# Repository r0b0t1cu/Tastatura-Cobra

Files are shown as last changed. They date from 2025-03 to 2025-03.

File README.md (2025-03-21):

# [RO] Tastatură Custom pentru Cobra & ZX Spectrum  

Acesta este un proiect open-source pentru o tastatură mecanică compatibilă cu computerul românesc **Cobra** și alte clone **ZX Spectrum**.
Tastatura a fost proiectată pentru a fi ușor de construit, utilizând componente accesibile.  

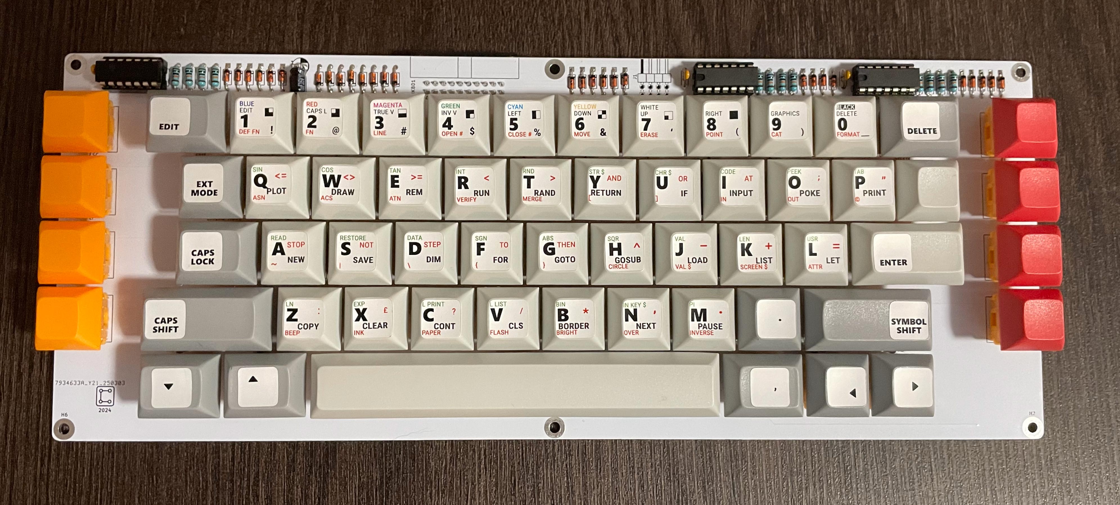
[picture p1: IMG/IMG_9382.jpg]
Tastatură completă


## Caracteristici  
- **Compatibilitate:** Cobra, ZX Spectrum și clone  
- **Conexiune:** Cablu panglică 2x10, conector montat pe partea inferioară a PCB-ului
- **Componente principale:**  
  - 59 Switch-uri mecanice cu 3 pini din plastic  
  - 3 x **IC CD4066**  
  - 29 x **diode BAT42**  
  - 12 x **rezistențe 100k**  
  - 1 x **condensator 10uF**  
  - 3 x **condensator 100nF**  
  - 1 x **conector 2x10 pini**  
  - optional - 1 x **conector 2x4 pini**
- **Funcționalitate extinsă:**
  - Taste speciale pentru CP/M pe Cobra
  - Taste separate pentru: del, cursor, caps lock, edit, extended mode, "." (punct), "," (virgula), ":" (doua puncte)

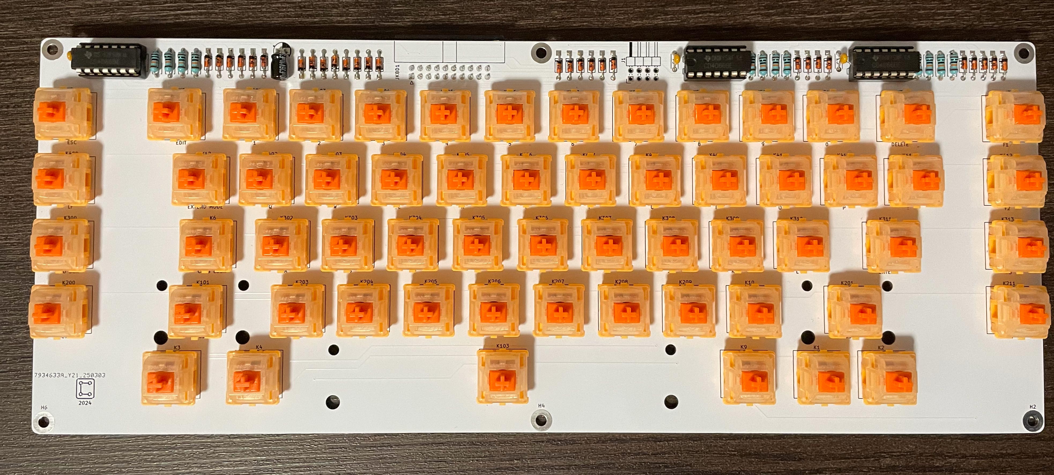
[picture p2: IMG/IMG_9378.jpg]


## Instalare și Conectare  
1. **Montaj PCB:** Conectorul cablului panglică **trebuie montat pe partea inferioară** a PCB-ului.  
2. **Pentru Cobra:** Se conectează direct la interfața tastaturii.  
3. **Pentru ZX Spectrum și clone:** Se identifică manual liniile și coloanele din matrice și se ajustează conexiunile corespunzător. 
4. Tastatura este gândită să se potrivească pe carcasa de aici:
   - [https://www.z80-romania.ro/CoBra-64](https://www.z80-romania.ro/CoBra-64)  
   - Fișiere: [Download CoBra Case (ZIP)](https://www.z80-romania.ro/files/64/Carcasa%20CoBra%20-%20cobrasov.com%20(2024).zip?1708896374)

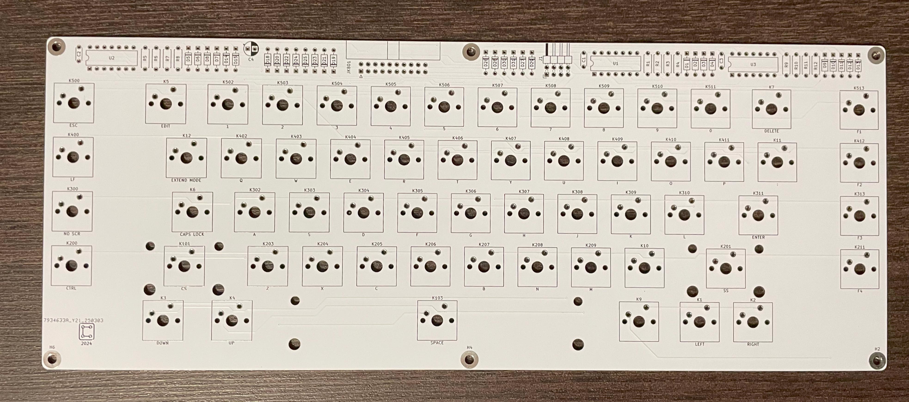
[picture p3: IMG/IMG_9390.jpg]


## Fișiere Disponibile  
- **Schematica și PCB:** Fișiere KiCad în folderul KICAD
- **Fișiere Gerber:** Pentru fabricarea PCB-ului în folderul PRODUCTION
- **BOM:** În folderul BOM
- **Grafica pentru stickere taste:** În folderul PDF
- **Schema:** În folderul PDF

## Surse și Mulțumiri  
Informațiile din acest proiect au fost inspirate și dezvoltate pe baza resurselor de la:  
- [cobrasov.com](https://cobrasov.com)  
- [CherryZXKeyboard](https://github.com/VlastimilWagner/CherryZXKeyboard)
- Și cu observații și input prețios de la [svpantazi](https://github.com/svpantazi)  

## Licență  
Acest proiect este **complet liber** pentru oricine dorește să-l folosească, modifice sau îmbunătățească.

# [EN] Custom Keyboard for Cobra & ZX Spectrum  

This is an open-source project for a mechanical keyboard compatible with the Romanian **Cobra** computer and other **ZX Spectrum clones**.  
The keyboard is designed to be easy to build, using readily available components.  

## Features  
- **Compatibility:** Cobra, ZX Spectrum, and clones  
- **Connection:** 2x10 ribbon cable, connector mounted on the **bottom side** of the PCB  
- **Main components:**  
  - 59 **mechanical switches** (3-pin plastic)  
  - 3 x **IC CD4066**  
  - 29 x **BAT42 diodes**  
  - 12 x **100k resistors**  
  - 1 x **10µF capacitor**  
  - 3 x **100nF capacitors**  
  - 1 x **2x10-pin connector**  
  - Optional: 1 x **2x4-pin connector**  
- **Extended functionality:**  
  - Special keys for CP/M on Cobra  
  - Separate keys for: Delete, Cursor, Caps Lock, Edit, Extended Mode, ".", ",", ":"  

## Installation & Connection  
1. **PCB Assembly:** The ribbon cable **must be mounted on the bottom side** of the PCB.  
2. **For Cobra:** Connects directly to the keyboard interface.  
3. **For ZX Spectrum and clones:** Manually identify the matrix rows and columns and adjust the connections accordingly.  
4. The keyboard is designed to fit in the case from:  
   - [https://www.z80-romania.ro/CoBra-64](https://www.z80-romania.ro/CoBra-64)  
   - Case files: [Download CoBra Case (ZIP)](https://www.z80-romania.ro/files/64/Carcasa%20CoBra%20-%20cobrasov.com%20(2024).zip?1708896374)

## Available Files  
- **Schematics & PCB:** KiCad files in the **KICAD** folder  
- **Gerber Files:** For PCB fabrication in the **PRODUCTION** folder  
- **BOM (Bill of Materials):** Located in the **BOM** folder  
- **Keycap Sticker Graphics:** In the **PDF** folder  
- **Schematic Diagram:** In the **PDF** folder  

## Sources & Acknowledgments  
This project was inspired and developed using information from:  
- [cobrasov.com](https://cobrasov.com)  
- [CherryZXKeyboard](https://github.com/VlastimilWagner/CherryZXKeyboard)  
- With valuable insights and feedback from [svpantazi](https://github.com/svpantazi)  

## License  
This project is **completely free** for anyone to use, modify, or improve.

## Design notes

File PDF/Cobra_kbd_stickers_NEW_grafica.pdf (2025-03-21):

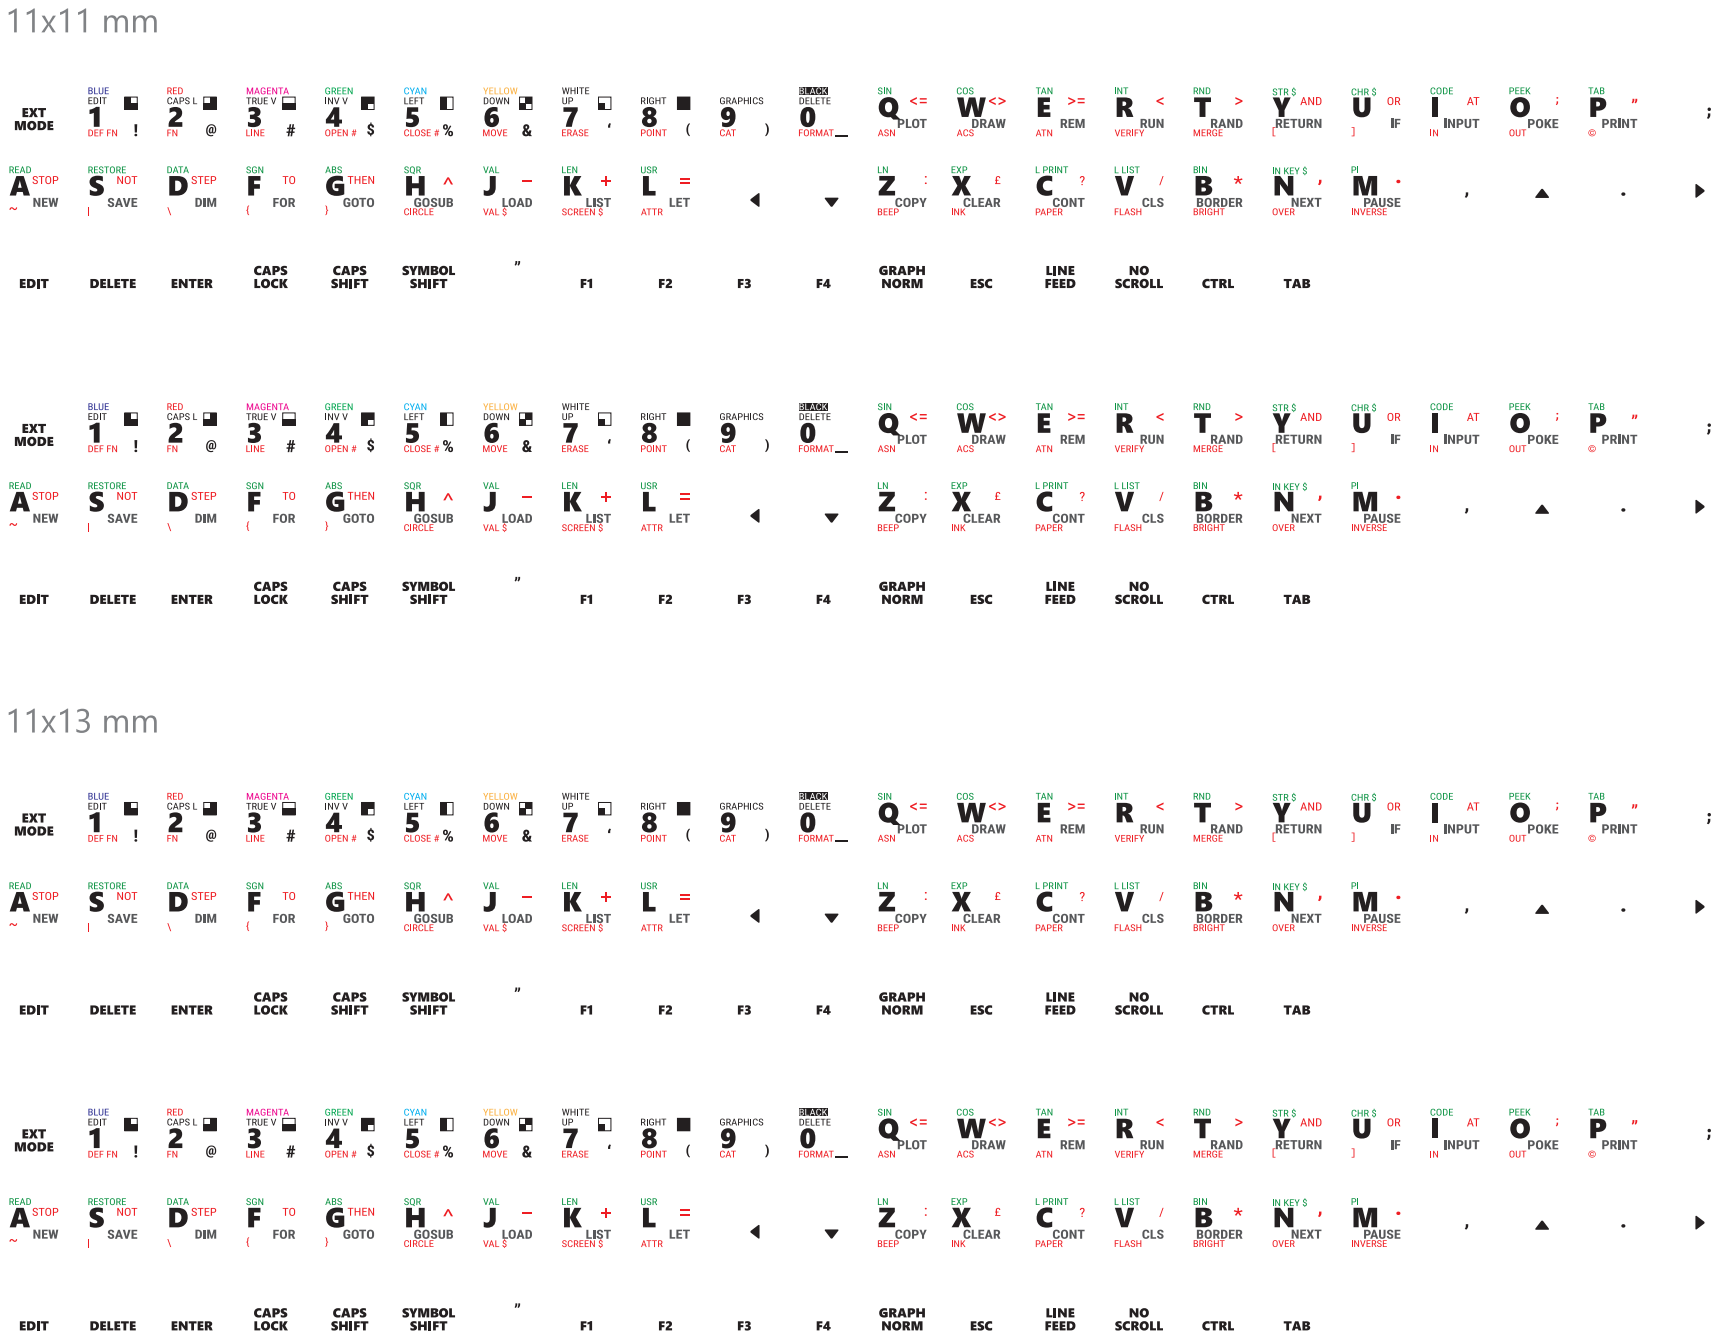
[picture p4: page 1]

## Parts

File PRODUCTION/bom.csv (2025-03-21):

Designator | Footprint | Quantity | Value | LCSC Part #
C1, C2, C3 | C_Disc_D4.3mm_W1.9mm_P5.00mm | 3 | 100nF
C4 | CP_Radial_D5.0mm_P2.50mm | 1 | 10uF
D1, D10, D11, D12, D13, D14, D15, D18, D19, D2, D20, D21, D22, D23, D24, D25, D26, D27, D28, D29, D3, D30, D31, D4, D5, D6, D7, D8, D9 | D_DO-35_SOD27_P7.62mm_Horizontal | 29 | BAT42
J1 | PinHeader_2x04_P2.54mm_Horizontal | 1 | Conn_01x08_Pin
JKBD1 | IDC-Header_2x10_P2.54mm_Horizontal | 1 | Conn_KBD
K1 | SW_Cherry_MX_1.00u_PCB | 1 | LEFT
K10 | SW_Cherry_MX_1.00u_PCB | 1 | .
K101 | SW_Cherry_MX_2.00u_PCB | 1 | CS
K103 | SW_Cherry_MX_6.25u_PCB | 1 | SPACE
K11 | SW_Cherry_MX_1.00u_PCB | 1 | :
K12 | SW_Cherry_MX_1.00u_PCB | 1 | EXTEND MODE
K2 | SW_Cherry_MX_1.00u_PCB | 1 | RIGHT
K200 | SW_Cherry_MX_1.00u_PCB | 1 | CTRL
K201 | SW_Cherry_MX_2.00u_PCB | 1 | SS
K203 | SW_Cherry_MX_1.00u_PCB | 1 | Z
K204 | SW_Cherry_MX_1.00u_PCB | 1 | X
K205 | SW_Cherry_MX_1.00u_PCB | 1 | C
K206 | SW_Cherry_MX_1.00u_PCB | 1 | V
K207 | SW_Cherry_MX_1.00u_PCB | 1 | B
K208 | SW_Cherry_MX_1.00u_PCB | 1 | N
K209 | SW_Cherry_MX_1.00u_PCB | 1 | M
K211 | SW_Cherry_MX_1.00u_PCB | 1 | F4
K3 | SW_Cherry_MX_1.25u_PCB | 1 | DOWN
K300 | SW_Cherry_MX_1.00u_PCB | 1 | NO SCR
K302 | SW_Cherry_MX_1.00u_PCB | 1 | A
K303 | SW_Cherry_MX_1.00u_PCB | 1 | S
K304 | SW_Cherry_MX_1.00u_PCB | 1 | D
K305 | SW_Cherry_MX_1.00u_PCB | 1 | F
K306 | SW_Cherry_MX_1.00u_PCB | 1 | G
K307 | SW_Cherry_MX_1.00u_PCB | 1 | H
K308 | SW_Cherry_MX_1.00u_PCB | 1 | J
K309 | SW_Cherry_MX_1.00u_PCB | 1 | K
K310 | SW_Cherry_MX_1.00u_PCB | 1 | L
K311 | SW_Cherry_MX_1.75u_PCB | 1 | ENTER
K313 | SW_Cherry_MX_1.00u_PCB | 1 | F3
K4 | SW_Cherry_MX_1.25u_PCB | 1 | UP
K400 | SW_Cherry_MX_1.00u_PCB | 1 | LF
K402 | SW_Cherry_MX_1.00u_PCB | 1 | Q
K403 | SW_Cherry_MX_1.00u_PCB | 1 | W
K404 | SW_Cherry_MX_1.00u_PCB | 1 | E
K405 | SW_Cherry_MX_1.00u_PCB | 1 | R
K406 | SW_Cherry_MX_1.00u_PCB | 1 | T
K407 | SW_Cherry_MX_1.00u_PCB | 1 | Y
K408 | SW_Cherry_MX_1.00u_PCB | 1 | U
K409 | SW_Cherry_MX_1.00u_PCB | 1 | I
K410 | SW_Cherry_MX_1.00u_PCB | 1 | O
K411 | SW_Cherry_MX_1.00u_PCB | 1 | P
K412 | SW_Cherry_MX_1.00u_PCB | 1 | F2
K5 | SW_Cherry_MX_1.25u_PCB | 1 | EDIT
K500 | SW_Cherry_MX_1.00u_PCB | 1 | ESC
K502 | SW_Cherry_MX_1.00u_PCB | 1 | 1
K503 | SW_Cherry_MX_1.00u_PCB | 1 | 2
K504 | SW_Cherry_MX_1.00u_PCB | 1 | 3
K505 | SW_Cherry_MX_1.00u_PCB | 1 | 4
K506 | SW_Cherry_MX_1.00u_PCB | 1 | 5
K507 | SW_Cherry_MX_1.00u_PCB | 1 | 6
K508 | SW_Cherry_MX_1.00u_PCB | 1 | 7
K509 | SW_Cherry_MX_1.00u_PCB | 1 | 8
K510 | SW_Cherry_MX_1.00u_PCB | 1 | 9
K511 | SW_Cherry_MX_1.00u_PCB | 1 | 0
K513 | SW_Cherry_MX_1.00u_PCB | 1 | F1
K6 | SW_Cherry_MX_1.25u_PCB | 1 | CAPS LOCK
K7 | SW_Cherry_MX_1.25u_PCB | 1 | DELETE
K9 | SW_Cherry_MX_1.25u_PCB | 1 | ,
R1, R10, R11, R12, R2, R3, R4, R5, R6, R7, R8, R9 | R_Axial_DIN0207_L6.3mm_D2.5mm_P7.62mm_Horizontal | 12 | 100k
U1, U2, U3 | DIP-14_W7.62mm | 3 | CD4066BE

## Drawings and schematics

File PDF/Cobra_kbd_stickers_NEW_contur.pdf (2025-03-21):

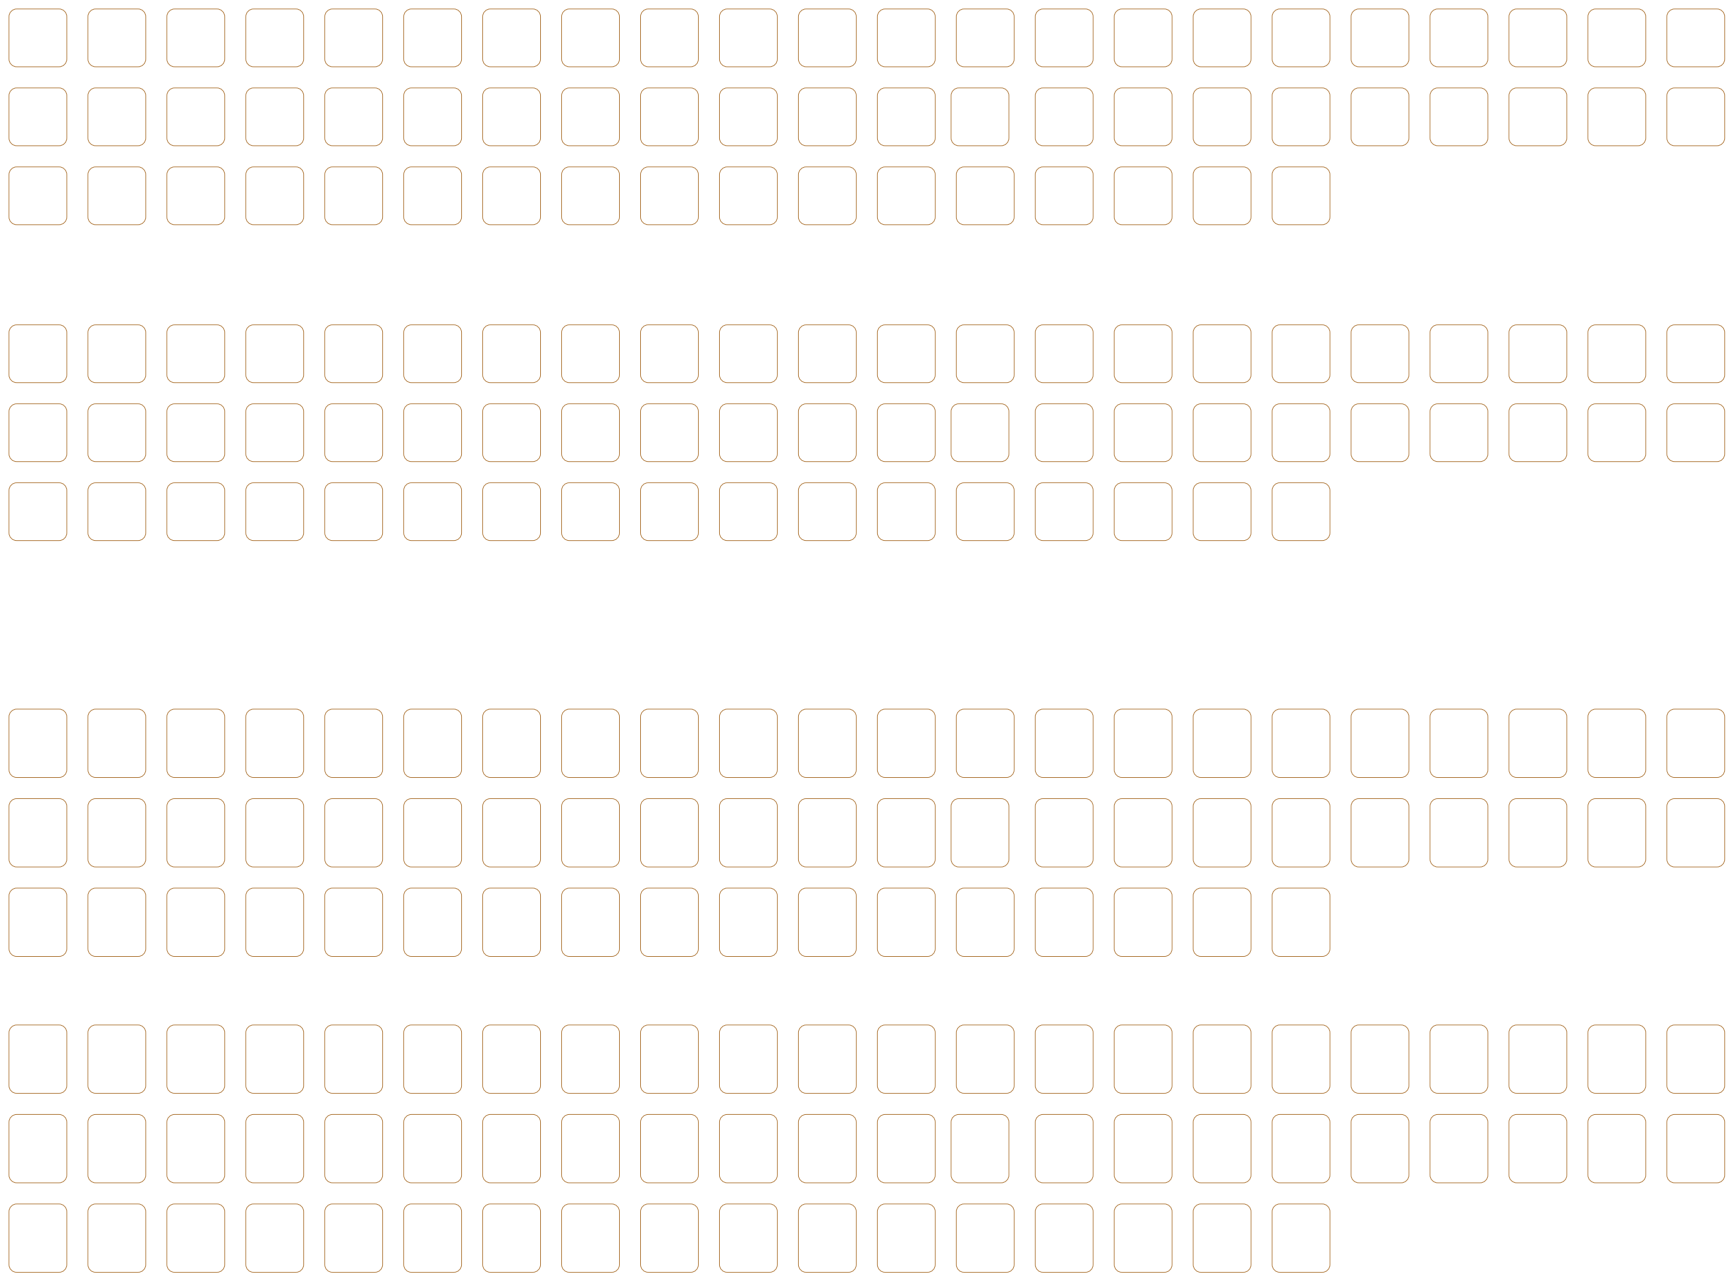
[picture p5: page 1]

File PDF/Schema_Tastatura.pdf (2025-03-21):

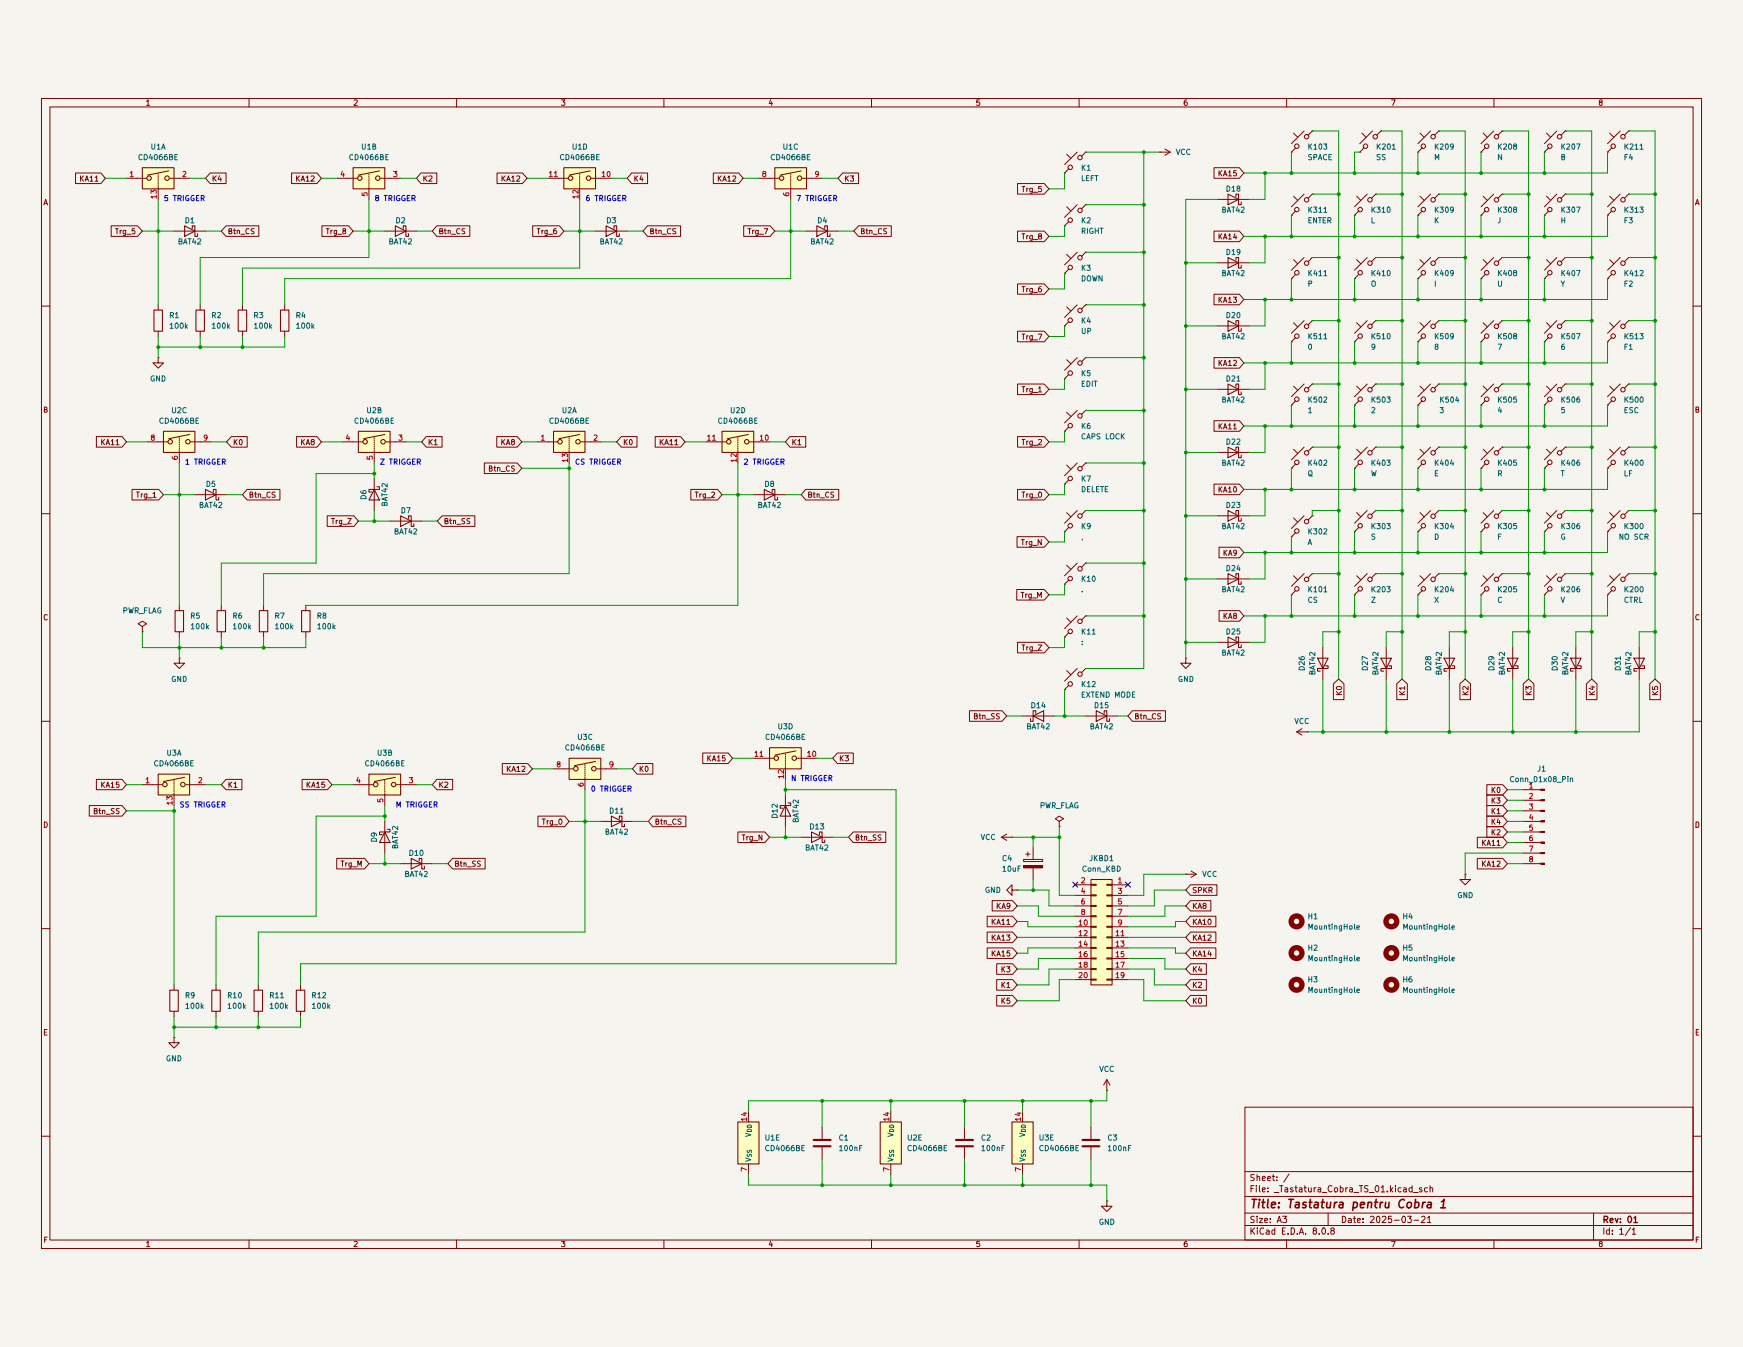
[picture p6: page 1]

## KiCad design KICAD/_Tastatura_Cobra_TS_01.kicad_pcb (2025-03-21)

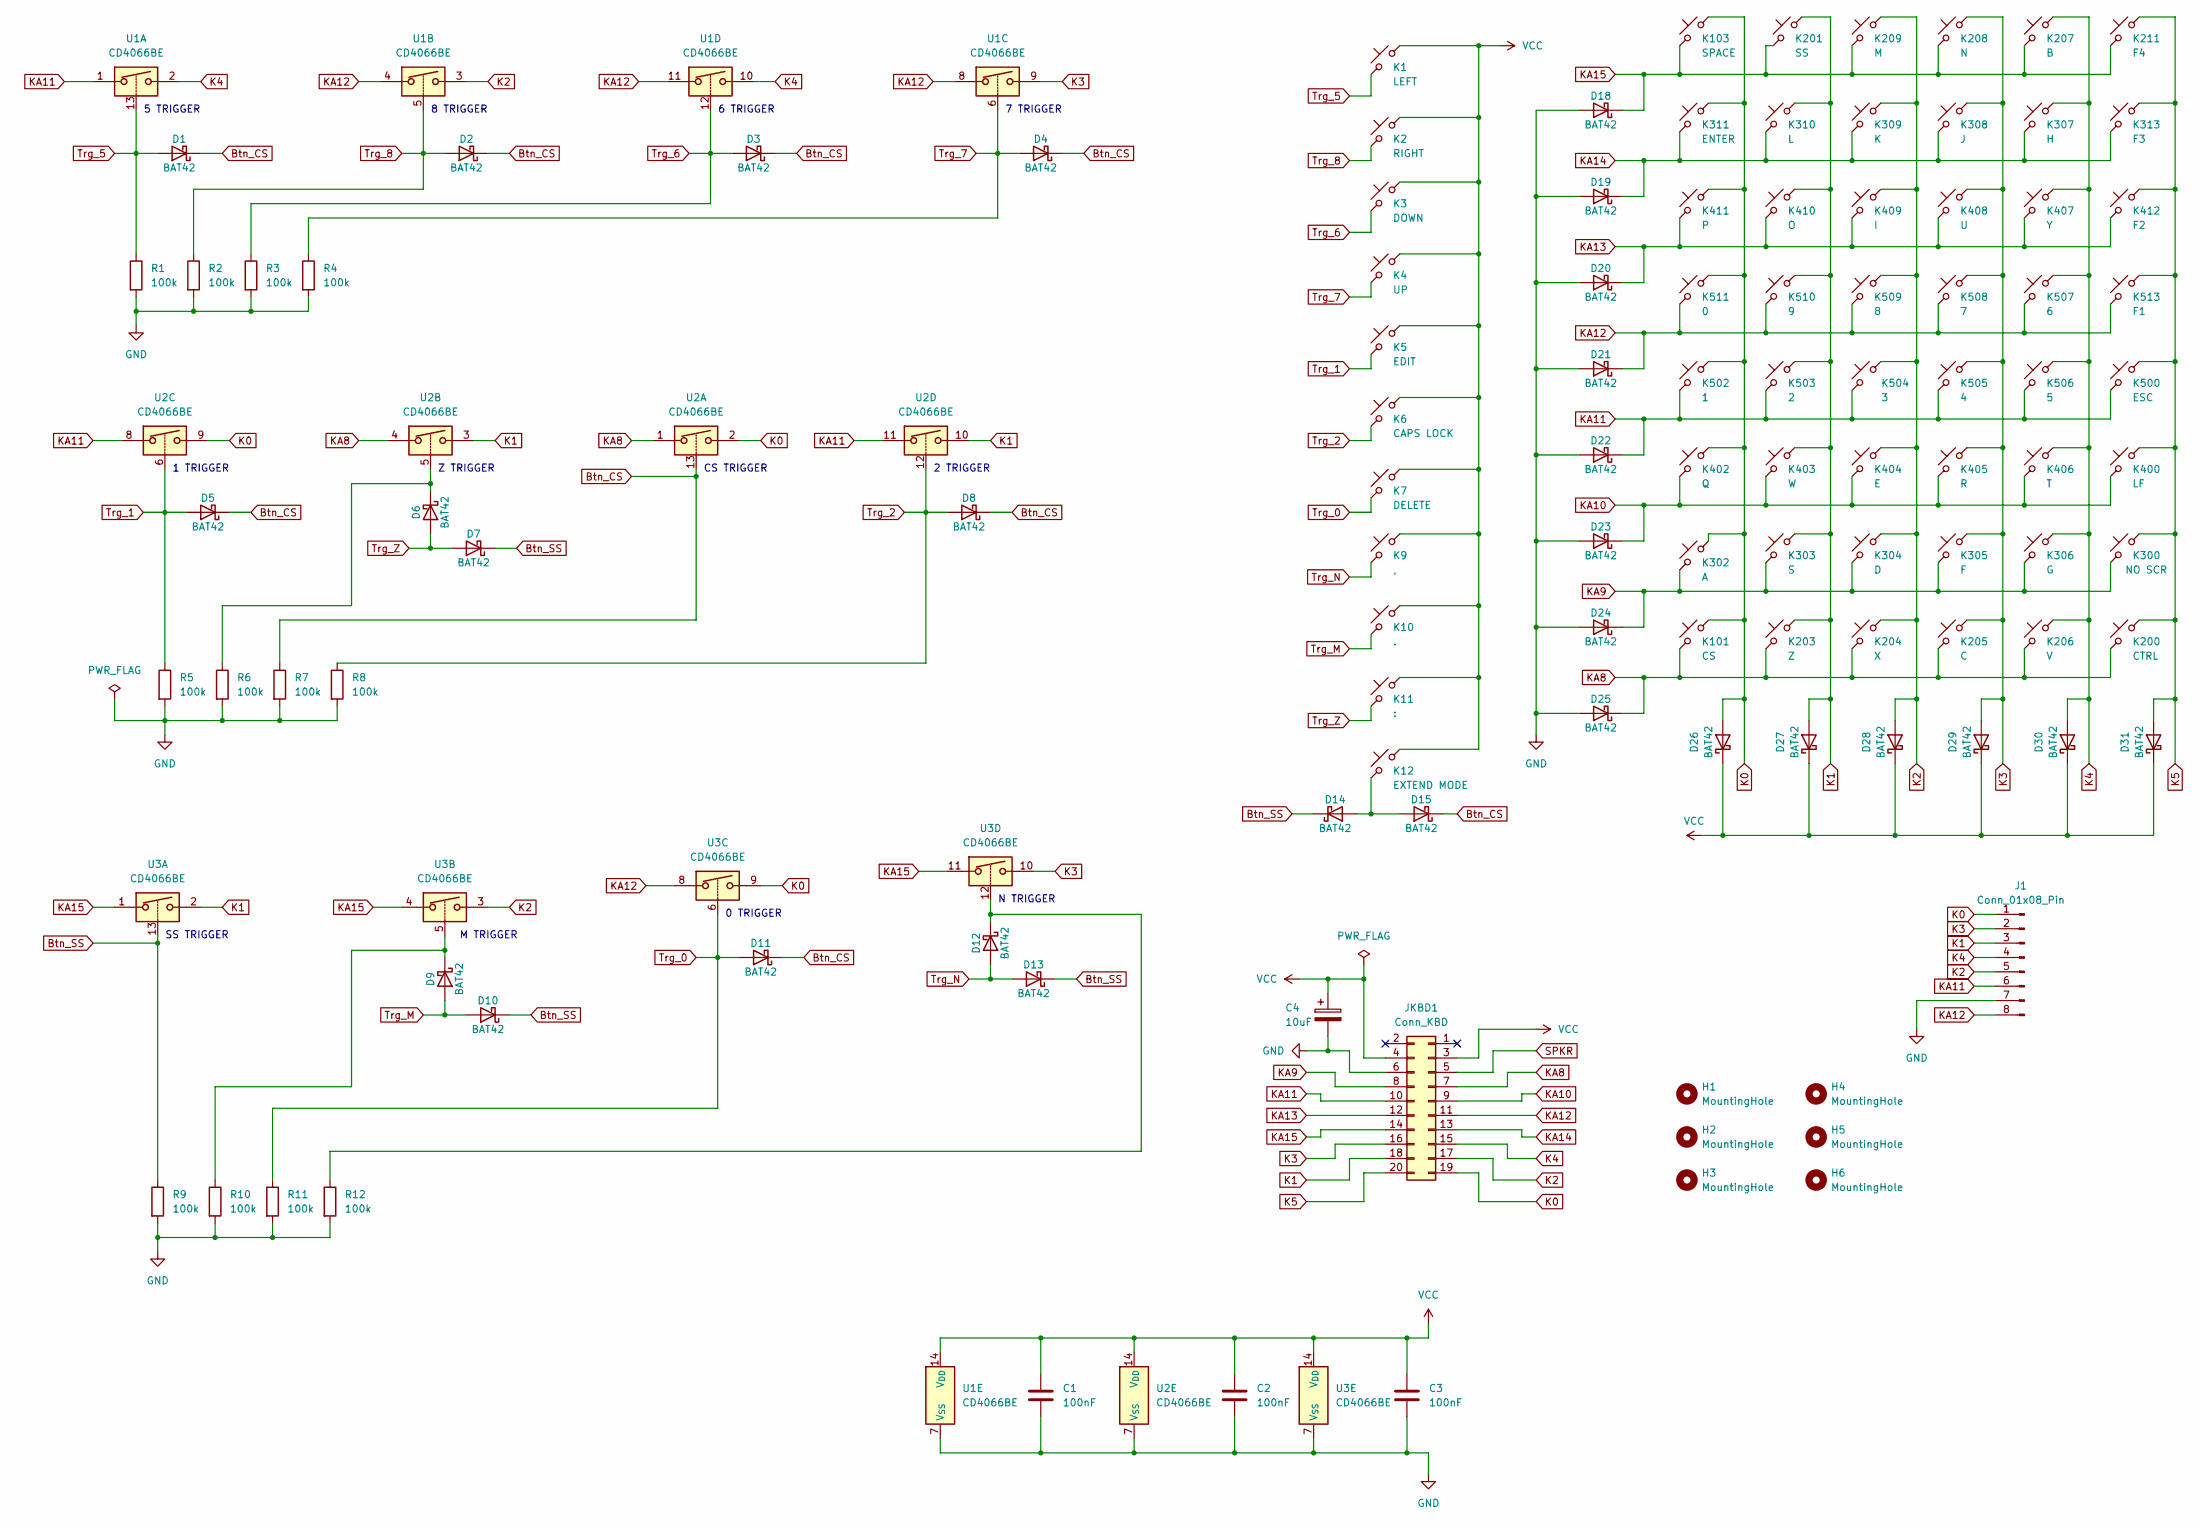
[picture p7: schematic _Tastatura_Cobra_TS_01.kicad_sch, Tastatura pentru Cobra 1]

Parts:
C1, C2, C3: 100nF; C_Disc_D4.3mm_W1.9mm_P5.00mm
C4: 10uF; CP_Radial_D5.0mm_P2.50mm
D1, D2, D3, D4, D5, D6, D7, D8, D9, D10, D11, D12, D13, D14, D15, D18, D19, D20, D21, D22, D23, D24, D25, D26, D27, D28, D29, D30, D31: BAT42; D_DO-35_SOD27_P7.62mm_Horizontal
H1, H2, H3, H4, H5, H6: MountingHole; MountingHole_3.2mm_M3_Pad_TopBottom
J1: Conn_01x08_Pin; PinHeader_2x04_P2.54mm_Horizontal
JKBD1: Conn_KBD; IDC-Header_2x10_P2.54mm_Horizontal
K1: LEFT; SW_Cherry_MX_1.00u_PCB
K2: RIGHT; SW_Cherry_MX_1.00u_PCB
K3: DOWN; SW_Cherry_MX_1.25u_PCB
K4: UP; SW_Cherry_MX_1.25u_PCB
K5: EDIT; SW_Cherry_MX_1.25u_PCB
K6: CAPS LOCK; SW_Cherry_MX_1.25u_PCB
K7: DELETE; SW_Cherry_MX_1.25u_PCB
K9: ,; SW_Cherry_MX_1.25u_PCB
K10: .; SW_Cherry_MX_1.00u_PCB
K11: :; SW_Cherry_MX_1.00u_PCB
K12: EXTEND MODE; SW_Cherry_MX_1.00u_PCB
K101: CS; SW_Cherry_MX_2.00u_PCB
K103: SPACE; SW_Cherry_MX_6.25u_PCB
K200: CTRL; SW_Cherry_MX_1.00u_PCB
K201: SS; SW_Cherry_MX_2.00u_PCB
K203: Z; SW_Cherry_MX_1.00u_PCB
K204: X; SW_Cherry_MX_1.00u_PCB
K205: C; SW_Cherry_MX_1.00u_PCB
K206: V; SW_Cherry_MX_1.00u_PCB
K207: B; SW_Cherry_MX_1.00u_PCB
K208: N; SW_Cherry_MX_1.00u_PCB
K209: M; SW_Cherry_MX_1.00u_PCB
K211: F4; SW_Cherry_MX_1.00u_PCB
K300: NO SCR; SW_Cherry_MX_1.00u_PCB
K302: A; SW_Cherry_MX_1.00u_PCB
K303: S; SW_Cherry_MX_1.00u_PCB
K304: D; SW_Cherry_MX_1.00u_PCB
K305: F; SW_Cherry_MX_1.00u_PCB
K306: G; SW_Cherry_MX_1.00u_PCB
K307: H; SW_Cherry_MX_1.00u_PCB
K308: J; SW_Cherry_MX_1.00u_PCB
K309: K; SW_Cherry_MX_1.00u_PCB
K310: L; SW_Cherry_MX_1.00u_PCB
K311: ENTER; SW_Cherry_MX_1.75u_PCB
K313: F3; SW_Cherry_MX_1.00u_PCB
K400: LF; SW_Cherry_MX_1.00u_PCB
K402: Q; SW_Cherry_MX_1.00u_PCB
K403: W; SW_Cherry_MX_1.00u_PCB
K404: E; SW_Cherry_MX_1.00u_PCB
K405: R; SW_Cherry_MX_1.00u_PCB
K406: T; SW_Cherry_MX_1.00u_PCB
K407: Y; SW_Cherry_MX_1.00u_PCB
K408: U; SW_Cherry_MX_1.00u_PCB
K409: I; SW_Cherry_MX_1.00u_PCB
K410: O; SW_Cherry_MX_1.00u_PCB
K411: P; SW_Cherry_MX_1.00u_PCB
K412: F2; SW_Cherry_MX_1.00u_PCB
K500: ESC; SW_Cherry_MX_1.00u_PCB
K502: 1; SW_Cherry_MX_1.00u_PCB
K503: 2; SW_Cherry_MX_1.00u_PCB
K504: 3; SW_Cherry_MX_1.00u_PCB
K505: 4; SW_Cherry_MX_1.00u_PCB
K506: 5; SW_Cherry_MX_1.00u_PCB
K507: 6; SW_Cherry_MX_1.00u_PCB
K508: 7; SW_Cherry_MX_1.00u_PCB
K509: 8; SW_Cherry_MX_1.00u_PCB
K510: 9; SW_Cherry_MX_1.00u_PCB
K511: 0; SW_Cherry_MX_1.00u_PCB
K513: F1; SW_Cherry_MX_1.00u_PCB
R1, R2, R3, R4, R5, R6, R7, R8, R9, R10, R11, R12: 100k; R_Axial_DIN0207_L6.3mm_D2.5mm_P7.62mm_Horizontal
U1, U2, U3: CD4066BE; DIP-14_W7.62mm

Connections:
Btn_CS: D1.1 (K), D2.1 (K), D3.1 (K), D4.1 (K), D5.1 (K), D8.1 (K), D11.1 (K), D15.1 (K), R7.1, U2.13
Btn_SS: D7.1 (K), D10.1 (K), D13.1 (K), D14.1 (K), R9.1, U3.13
GND: C1.2, C2.2, C3.2, C4.2, D18.2 (A), D19.2 (A), D20.2 (A), D21.2 (A), D22.2 (A), D23.2 (A), D24.2 (A), D25.2 (A), J1.7, JKBD1.6, R1.2, R2.2, R3.2, R4.2, R5.2, R6.2, R7.2, R8.2, R9.2, R10.2, R11.2, R12.2, U1.7 (V_{SS}), U2.7 (V_{SS}), U3.7 (V_{SS})
K0: D26.2 (A), J1.1, JKBD1.19, K101.2, K103.2, K302.2, K311.2, K402.2, K411.2, K502.2, K511.2, U2.2, U2.9, U3.9
K1: D27.2 (A), J1.3, JKBD1.18, K201.2, K203.2, K303.2, K310.2, K403.2, K410.2, K503.2, K510.2, U2.3, U2.10, U3.2
K2: D28.2 (A), J1.5, JKBD1.17, K204.2, K209.2, K304.2, K309.2, K404.2, K409.2, K504.2, K509.2, U1.3, U3.3
K3: D29.2 (A), J1.2, JKBD1.16, K205.2, K208.2, K305.2, K308.2, K405.2, K408.2, K505.2, K508.2, U1.9, U3.10
K4: D30.2 (A), J1.4, JKBD1.15, K206.2, K207.2, K306.2, K307.2, K406.2, K407.2, K506.2, K507.2, U1.2, U1.10
K5: D31.2 (A), JKBD1.20, K200.2, K211.2, K300.2, K313.2, K400.2, K412.2, K500.2, K513.2
KA8: D25.1 (K), JKBD1.7, K101.1, K200.1, K203.1, K204.1, K205.1, K206.1, U2.1, U2.4
KA9: D24.1 (K), JKBD1.8, K300.1, K302.1, K303.1, K304.1, K305.1, K306.1
KA10: D23.1 (K), JKBD1.9, K400.1, K402.1, K403.1, K404.1, K405.1, K406.1
KA11: D22.1 (K), J1.6, JKBD1.10, K500.1, K502.1, K503.1, K504.1, K505.1, K506.1, U1.1, U2.8, U2.11
KA12: D21.1 (K), J1.8, JKBD1.11, K507.1, K508.1, K509.1, K510.1, K511.1, K513.1, U1.4, U1.8, U1.11, U3.8
KA13: D20.1 (K), JKBD1.12, K407.1, K408.1, K409.1, K410.1, K411.1, K412.1
KA14: D19.1 (K), JKBD1.13, K307.1, K308.1, K309.1, K310.1, K311.1, K313.1
KA15: D18.1 (K), JKBD1.14, K103.1, K201.1, K207.1, K208.1, K209.1, K211.1, U3.1, U3.4, U3.11
unnamed: D6.1 (K), R6.1, U2.5
unnamed: D9.1 (K), R10.1, U3.5
unnamed: D12.1 (K), R12.1, U3.12
unnamed: D14.2 (A), D15.2 (A), K12.2
SPKR: JKBD1.5
Trg_0: D11.2 (A), K7.2, R11.1, U3.6
Trg_1: D5.2 (A), K5.2, R5.1, U2.6
Trg_2: D8.2 (A), K6.2, R8.1, U2.12
Trg_5: D1.2 (A), K1.2, R1.1, U1.13
Trg_6: D3.2 (A), K3.2, R3.1, U1.12
Trg_7: D4.2 (A), K4.2, R4.1, U1.6
Trg_8: D2.2 (A), K2.2, R2.1, U1.5
Trg_M: D9.2 (A), D10.2 (A), K10.2
Trg_N: D12.2 (A), D13.2 (A), K9.2
Trg_Z: D6.2 (A), D7.2 (A), K11.2
VCC: C1.1, C2.1, C3.1, C4.1, D26.1 (K), D27.1 (K), D28.1 (K), D29.1 (K), D30.1 (K), D31.1 (K), JKBD1.3, JKBD1.4, K1.1, K2.1, K3.1, K4.1, K5.1, K6.1, K7.1, K9.1, K10.1, K11.1, K12.1, U1.14 (V_{DD}), U2.14 (V_{DD}), U3.14 (V_{DD})

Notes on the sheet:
1 TRIGGER
7 TRIGGER
0 TRIGGER
SS TRIGGER
8 TRIGGER
6 TRIGGER
2 TRIGGER
Z TRIGGER
CS TRIGGER
5 TRIGGER
N TRIGGER
M TRIGGER

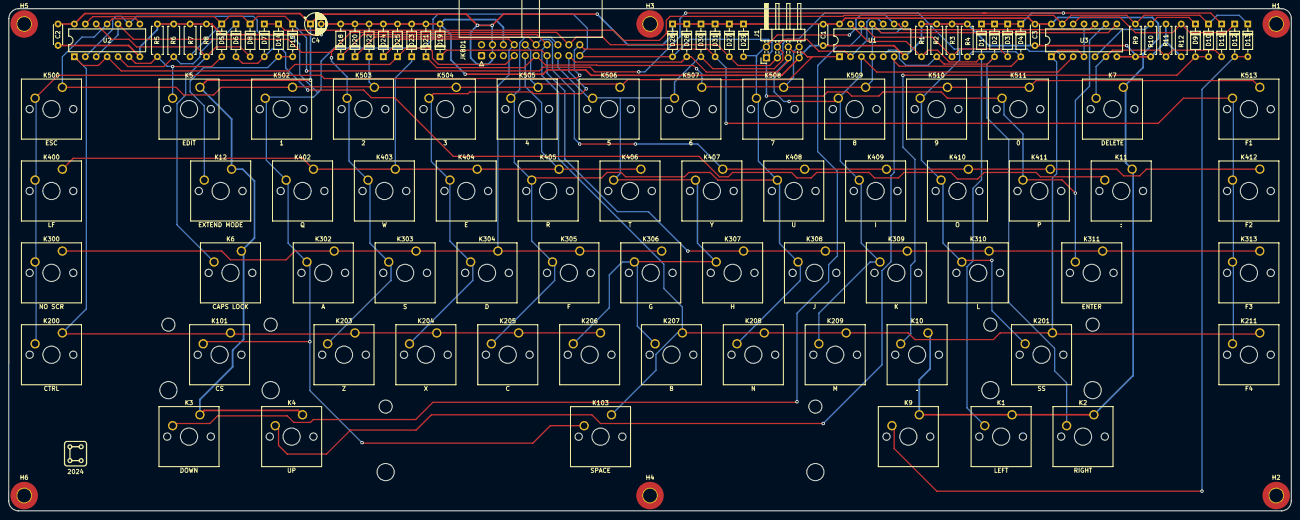
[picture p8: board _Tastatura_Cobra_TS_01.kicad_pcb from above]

Board: 2 copper layers, 298.4 x 116.8 mm, 115 parts (0 on the bottom side), 32 nets.
